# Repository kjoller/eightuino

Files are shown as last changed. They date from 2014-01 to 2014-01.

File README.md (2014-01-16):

eightuino
=========

Yet another arduino-like board, with the benefits of having a sane 2.54mm pin spacing. Also have the advantage of being a through-hole design, making it perfect for a beginner soldering project.

It is also cheap to build, as the board is less than the 5x5cm size required for the lowest price tier at several chinese prototyping serivces (IteadStudio, SeeedStudio, Elecrow).

The distance between the two rows of headers (17 mil) makes it suited for 5cm wide protoboards (which come very cheaply, as opposed to 'real' arduino proto-shields).

The project sprang out of a wish to improve my very first project, the [Cheapuino]

[Cheapuino]: http://lab.kjlr.dk/p/cheapuino

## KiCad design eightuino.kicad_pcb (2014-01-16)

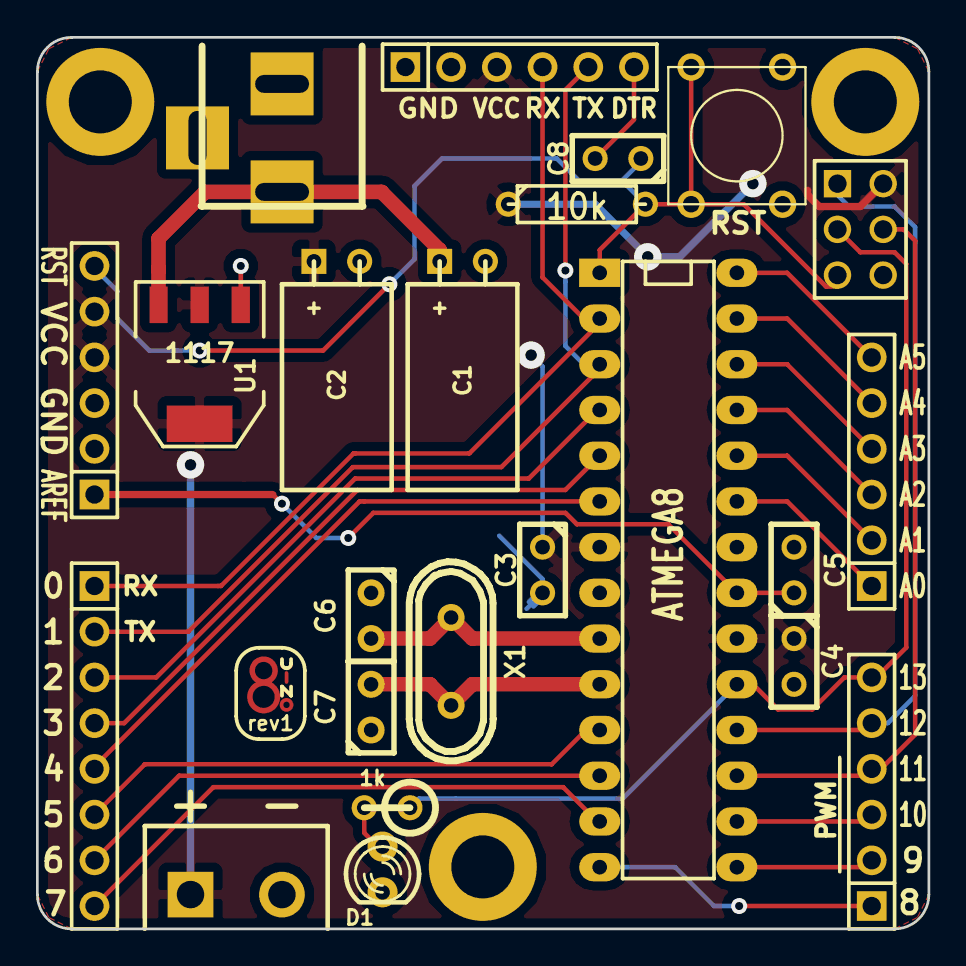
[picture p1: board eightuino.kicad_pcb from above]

Board: 2 copper layers, 49.5 x 49.5 mm, 28 parts (1 on the bottom side), 29 nets.

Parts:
1PIN, 1PIN#2, 1PIN#3: P***; 1pin
8uino2: rev1; 8uino_mix_silk+mask+copper
BT1: Unregulated Battery; bornier2
C1, C2: CP1; C1V5H
C3, C4, C5, C8: 100nF; C1
C6, C7: 22pF; cnp_3mm_disc
CON1: BARREL_JACK
D1: LED; LED-3MM
IC1: ATMEGA8; DIP-28__300_ELL
P1: PowerPins; Pinrow_6p
P2: Analog; Pinrow_6p
P3: Digital1; Pinrow_8p
P4: Digital_2; Pinrow_6p
P5: Serial; Pinrow_6p
P6: ISP; pin_array_3x2
R1: 10k; R3
R2: 1k; R1
SW1: RST; SW_PUSH_SMALL
SYM: Symbol_OSHW-Logo_SilkScreen_07Jul2012
U1: 1117; SOT223
X1: CRYSTAL; Crystal_HC49-U_Vertical_RevA_09Aug2010

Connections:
/DTR: C8.2, P5.6
/MISO: IC1.18, P4.5, P6.1
/MOSI: IC1.17, P4.4, P6.4
/RST: C8.1, IC1.1, P1.6, P6.5, R1.2, SW1.2
/RX: IC1.2, P3.1, P5.4
/SCK: IC1.19, P4.6, P6.3, R2.1
/TX: IC1.3, P3.2, P5.5
/XTAL1: C6.2, IC1.9, X1.2
/XTAL2: C7.2, IC1.10, X1.1
GND: 1PIN.1, 1PIN#2.1, 1PIN#3.1, BT1.2, C1.2, C2.2, C3.2, C4.2, C5.2, C6.1, C7.1, CON1.2, CON1.3, D1.2, IC1.8, IC1.22, P1.2, P1.3, P5.1, P5.2, P6.6, SW1.1, U1.1
unnamed: C1.1, CON1.1, U1.3
unnamed: C5.1, IC1.21, P1.1
unnamed: D1.1, R2.2
unnamed: IC1.4, P3.3
unnamed: IC1.5, P3.4
unnamed: IC1.6, P3.5
unnamed: IC1.11, P3.6
unnamed: IC1.12, P3.7
unnamed: IC1.13, P3.8
unnamed: IC1.14, P4.1
unnamed: IC1.15, P4.2
unnamed: IC1.16, P4.3
unnamed: IC1.23, P2.1
unnamed: IC1.24, P2.2
unnamed: IC1.25, P2.3
unnamed: IC1.26, P2.4
unnamed: IC1.27, P2.5
unnamed: IC1.28, P2.6
VCC: BT1.1, C2.1, C3.1, C4.1, IC1.7, IC1.20, P1.4, P1.5, P5.3, P6.2, R1.1, U1.2, U1.4

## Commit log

2014-01-14 Initial commit of project files
    [eightuino.kicad_pcb, eightuino.sch]
2014-01-14 Added FTDI connector in schematic
    [eightuino.sch]
2014-01-15 Changed schematic to 6-pin ISP
    [eightuino.sch]
2014-01-16 Almost total board rework.
    [eightuino-B_Cu.gbl, eightuino-B_Mask.gbs, eightuino-B_SilkS.gbo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]
2014-01-16 Remembered to save schematic
    [eightuino.sch]

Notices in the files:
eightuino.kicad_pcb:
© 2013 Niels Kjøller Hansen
